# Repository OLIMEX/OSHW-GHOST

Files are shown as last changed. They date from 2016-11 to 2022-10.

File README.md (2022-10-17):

# OSHW-GHOST
Small SMT soldering kit with PIC10F206 re-programmable microcontroller, capacitive sensor and LEDs

## License
* Hardware is released under CERN Open Hardware Licence Version 2 - Strongly Reciprocal https://spdx.org/licenses/CERN-OHL-S-2.0.html
* Software is released under GPL3 License
* Documentation is released under CC BY-SA 4.0 https://creativecommons.org/licenses/by-sa/4.0/

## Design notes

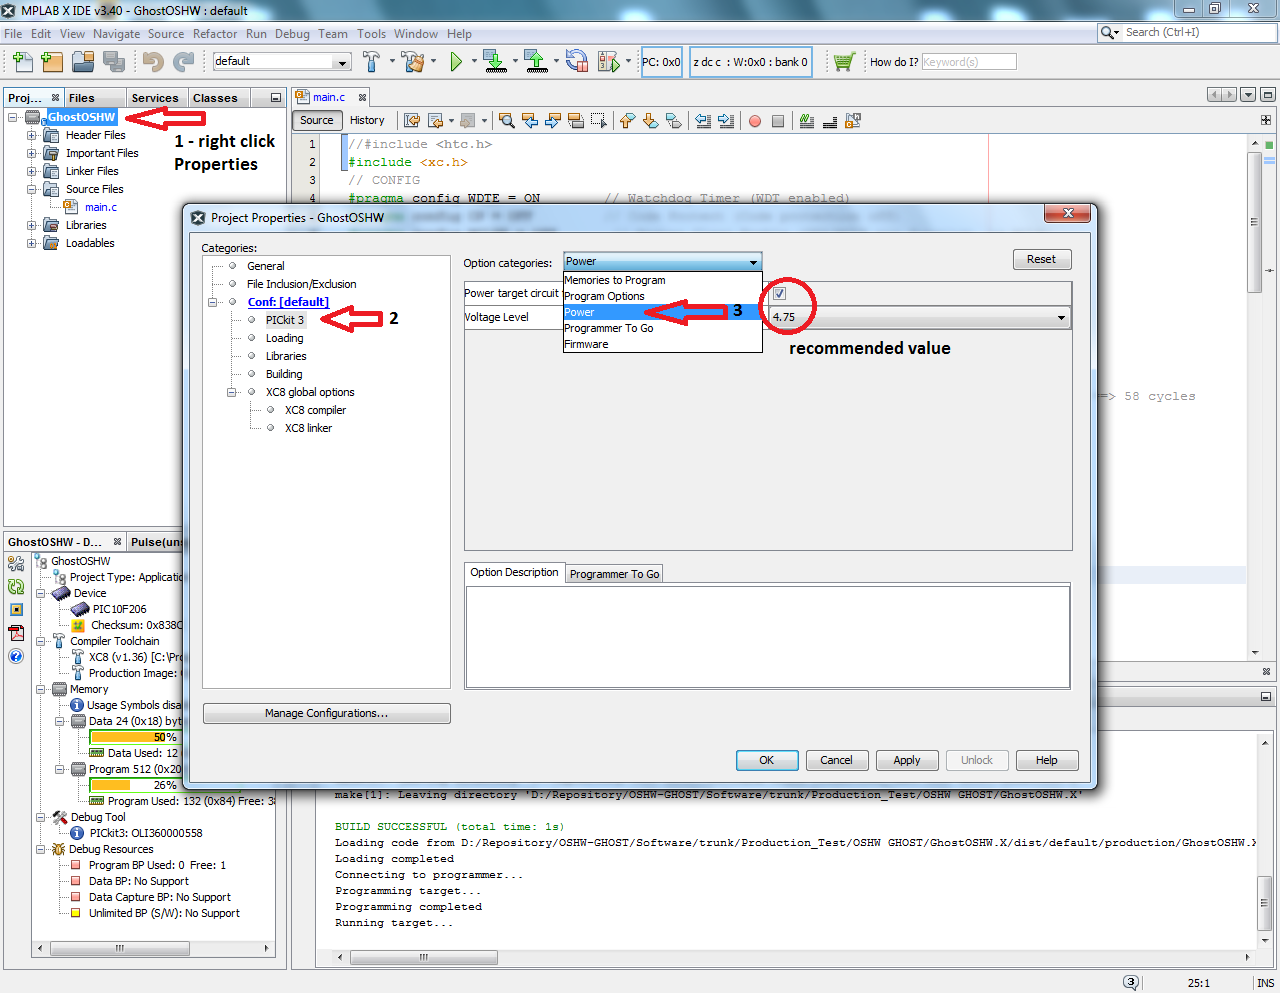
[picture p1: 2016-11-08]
SOFTWARE/voltage configuration.png

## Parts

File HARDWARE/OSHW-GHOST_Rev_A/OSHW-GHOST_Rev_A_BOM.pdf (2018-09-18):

### Sheet1

OSHW-GHOST_Rev_A
Quantity | Value | Device | Parts
1 | CR2032H_PTH | CR2032H_PTH | BAT_CON1
1 | 100nF/50V/20%/Y5V | C1206 | C1
1 | NA(WU06S) | ICSP-WU06S | ICSP1
2 | LED-3.0MM/GREEN | LED-3mm-PTH-KA | LED1,LED2
3 | 120R | R1206 | R1,R2,R4
1 | 1M | R1206 | R3
1 | NA(10k) | R1206 | R5
1 | PIC10F206T-I/OT | SOT23-6 | U1
1 | BADGE-PIN-CLIPS | BADGE-PIN-CLIPS | BPC1

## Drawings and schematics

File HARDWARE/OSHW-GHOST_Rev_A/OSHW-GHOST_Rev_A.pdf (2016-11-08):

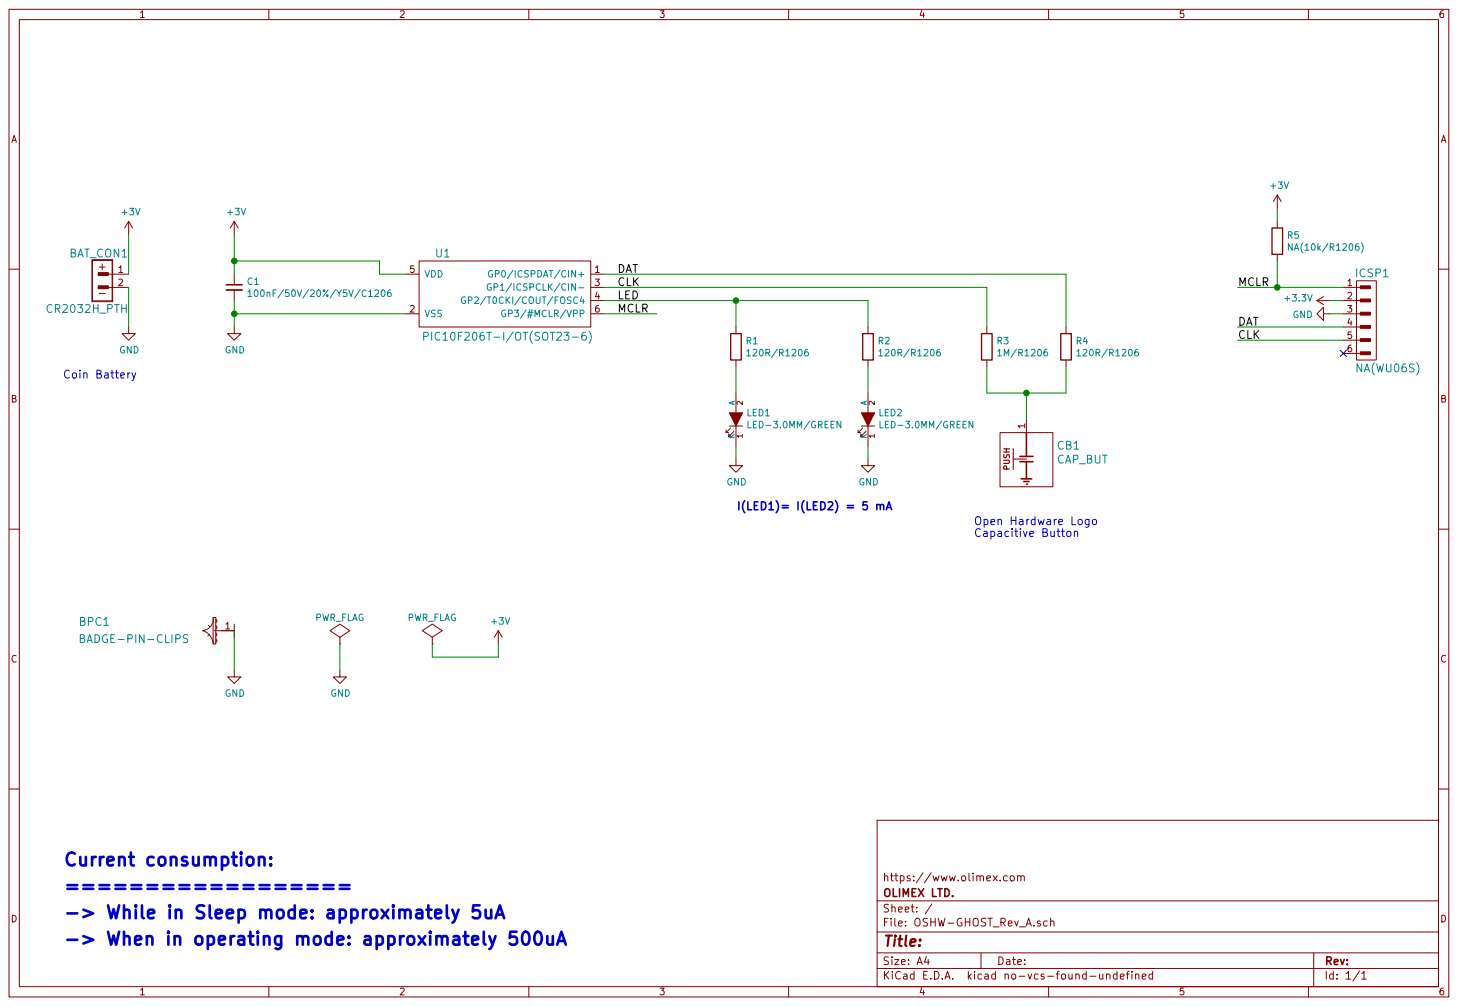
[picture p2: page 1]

NA(WU06S) R5NA(10k/R1206) +3.3V GND DAT CLK

File: OSHW-GHOST_Rev_A.sch Sheet: / OLIMEX LTD. https://www.olimex.com

-> While in Sleep mode: approximately 5uA
-> When in operating mode: approximately 500uA

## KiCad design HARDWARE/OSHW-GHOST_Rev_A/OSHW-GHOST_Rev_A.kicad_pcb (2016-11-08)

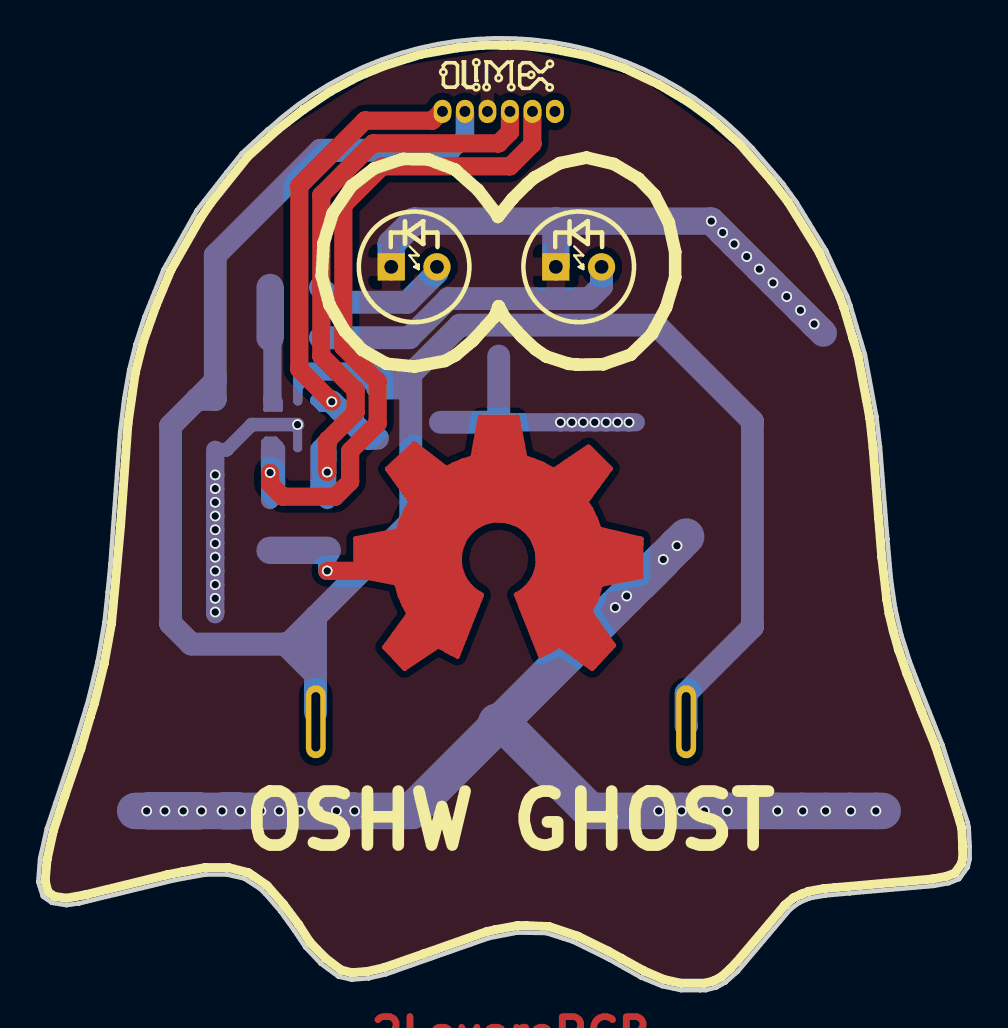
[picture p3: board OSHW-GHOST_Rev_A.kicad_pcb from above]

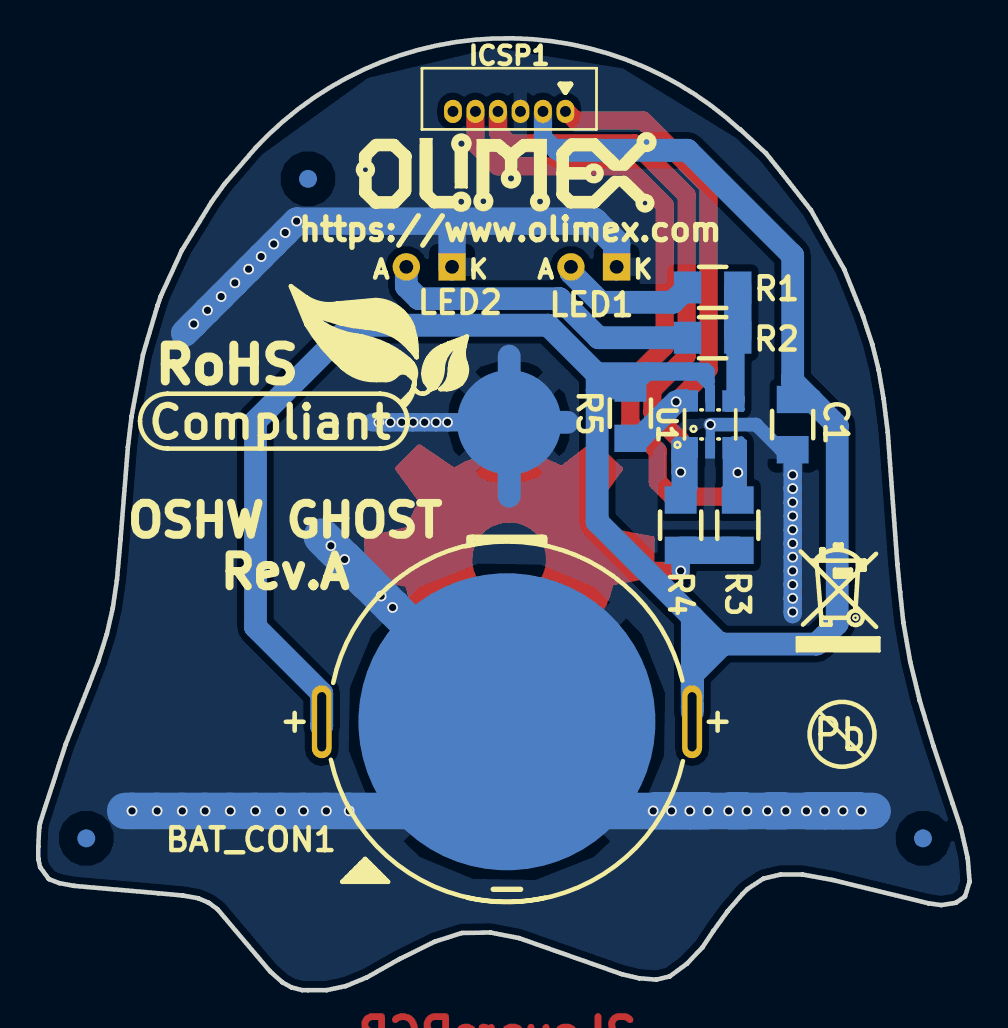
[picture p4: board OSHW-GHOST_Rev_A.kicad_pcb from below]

Board: 2 copper layers, 51.7 x 52.9 mm, 14 parts (11 on the bottom side), 9 nets.

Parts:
BAT_CON1: CR2032H_PTH
BPC1: BADGE-PIN-CLIPS
C1: 100nF/50V/20%/Y5V/C1206; C_1206_5MIL_DWS
CB1: CAP_BUT; CAP_BUT_LOGO_OPENHARDWARE_16x16
ICSP1: NA(WU06S); ICSP-WU06S
LED1, LED2: LED-3.0MM/GREEN; LED-3mm-PTH-KA
R1, R2, R4: 120R/R1206; R_1206_5MIL_DWS
R3: 1M/R1206; R_1206_5MIL_DWS
R5: NA(10k/R1206); R_1206_5MIL_DWS
Ref**: Val**; LOGO_ROHS_1
U1: PIC10F206T-I/OT(SOT23-6); SOT23-6

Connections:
+3V3: BAT_CON1.1, C1.1, ICSP1.2, R5.1, U1.5
/CLK: ICSP1.5, R3.1, U1.3
/DAT: ICSP1.4, R4.1, U1.1
/LED: R1.1, R2.1, U1.4
/MCLR: ICSP1.1, R5.2, U1.6
GND: BAT_CON1.2, BPC1.1, C1.2, ICSP1.3, LED1.1, LED2.1, U1.2
unnamed: CB1.1, R3.2, R4.2
unnamed: LED1.2, R1.2
unnamed: LED2.2, R2.2

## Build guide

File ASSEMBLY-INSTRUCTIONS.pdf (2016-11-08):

ASSEMBLY INSTRUCTIONS FOR OSHW-GHOST KIT

OSHW-GHOST is small open source hardware board, created to teach novices soldering SMT components. It’s easy to assembly and fun to use as it contain re-programmable PIC10F206 microcontroller which you can re-program yourself once you assembly the board.
Here is how the kit looks like:

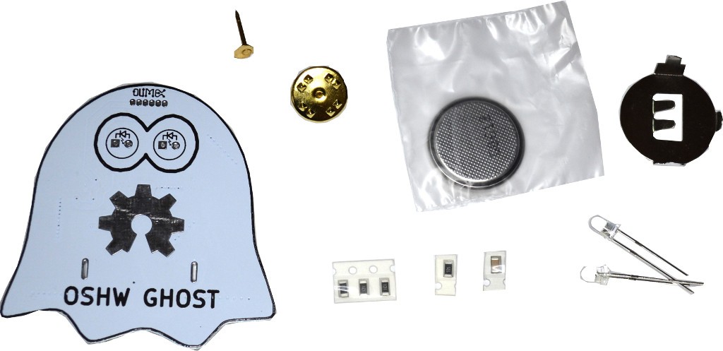
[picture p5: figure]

What you see is white printed circuit board, metal clip and pin which will allow you to attach this board to your cloths, battery and metal battery holder, 3 resistors one capacitor and two high intensity green LEDs with 3 mm diameter.

To solder this board you need:
- soldering iron, any with power 20-60W, thin tip and regulated temperature will do the job for instance this one; (https://www.olimex.com/Products/Tools/Soldering/CHN-SLD907/)
- solder with flux – we recommend to use 1 mm wire solder with 2.5% flux core;
- colophony (you can buy from any electronic store or music instruments store);
- tweezers like this one (https://www.olimex.com/Products/Tools/HandTools/CHN-TWZ2MM/) or similar;
- wire cutters like this one (https://www.olimex.com/Products/Tools/HandTools/PGC-TR25/) or similar;

Power up your soldering iron and set it to 300-350C temperature.
If you look at the PCB it comes with PIC microcontroller pre-soldered:

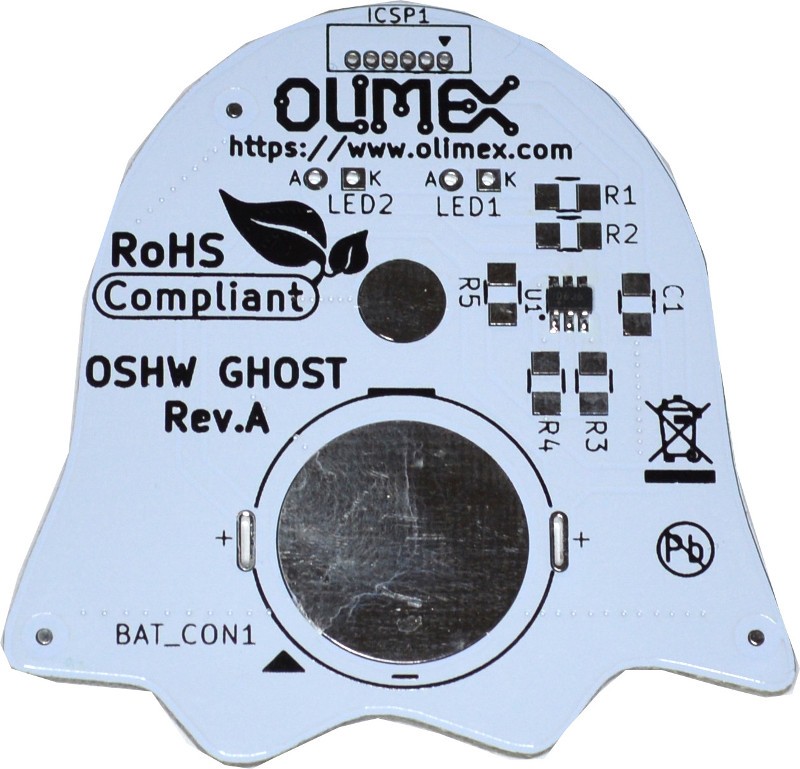
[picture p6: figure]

This is done intentionally for two reasons, first it’s hard to solder for novices, second to pre-program it we use the ICSP1 connector on top, to program this PIC microcontroller in bulk requires special adapter we do not have :)

First you find the brown rectangle component in the paper tape. This is 100 nF capacitor:

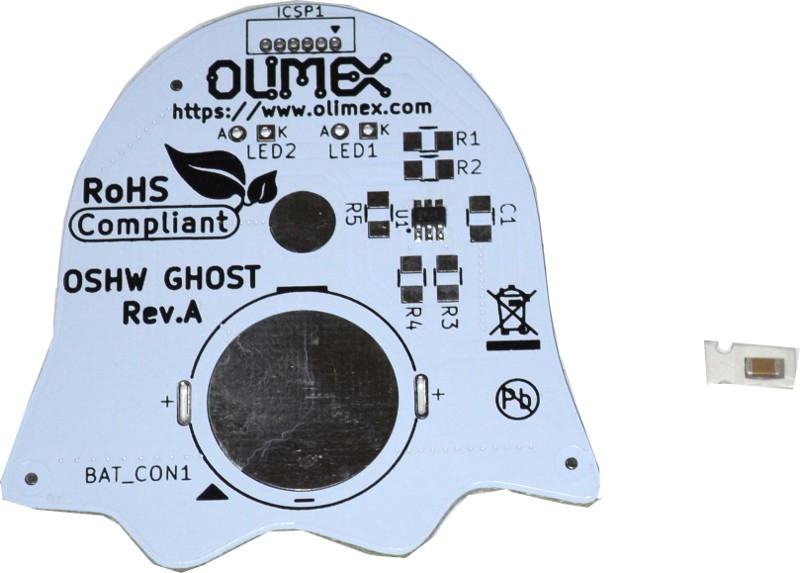
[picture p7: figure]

You must peel the transparent tape and take off the capacitor then to solder it to C1 pads on the board like on this picture.

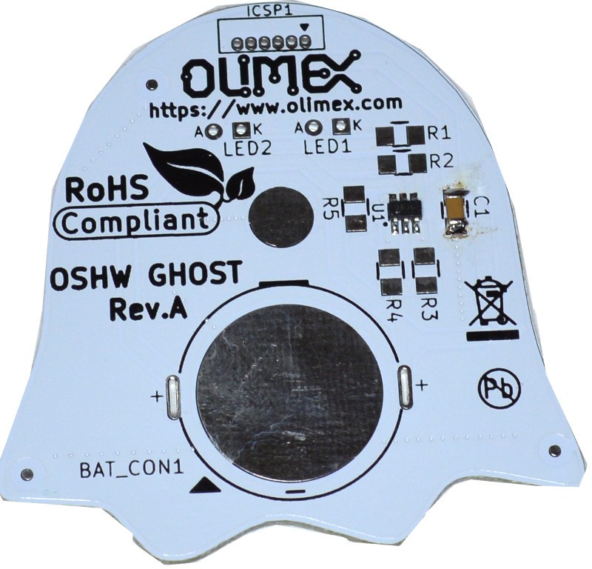
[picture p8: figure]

The colophony flux in the solder wire do a little messy look but do not worry, at the end you can use Isopropile or Ethyl alcohol with soft fabric to clean the flux residues. Even if not clean they are harmless for the board, just will not look pretty as the picture above :)

Once the capacitor is soldered at it’s place find the single black component in paper tape, it has marking 105. This is resistor with value 1 Mega Ohm. How this value 1Mega Ohm come from the 105 number? This three digit marking system for the resistor is composed by two digits and third which says how many zeros to add after the two digit so 105 = 10 00000 or 1 000 000 ohms (1Mega means 1 Million ohms). This resistor must be soldered at R3 pads on the PCB:

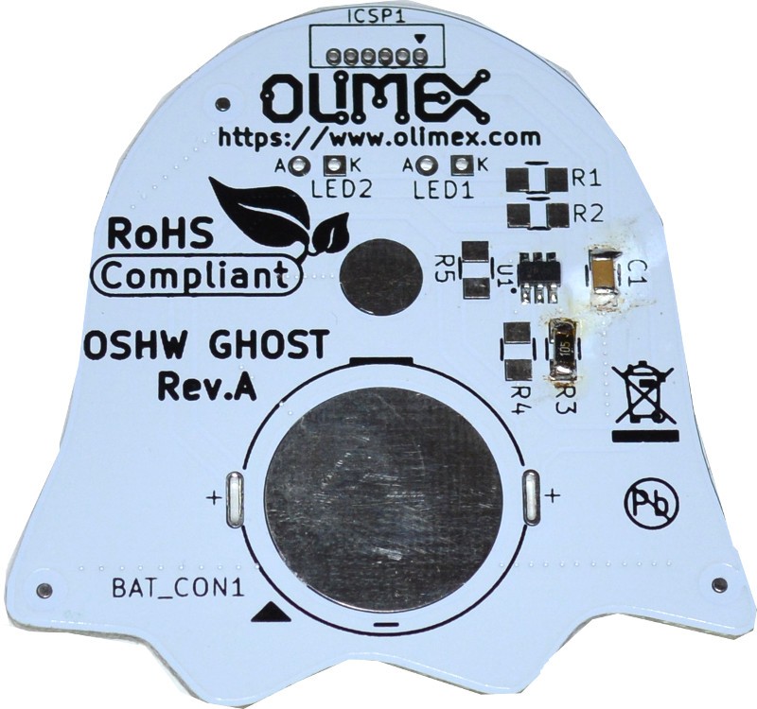
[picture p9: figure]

Then you need for find three resistors in paper tape, they are marked 121 = 120 or 120 Ohms! These must be soldered to R1, R2, and R4 locations:

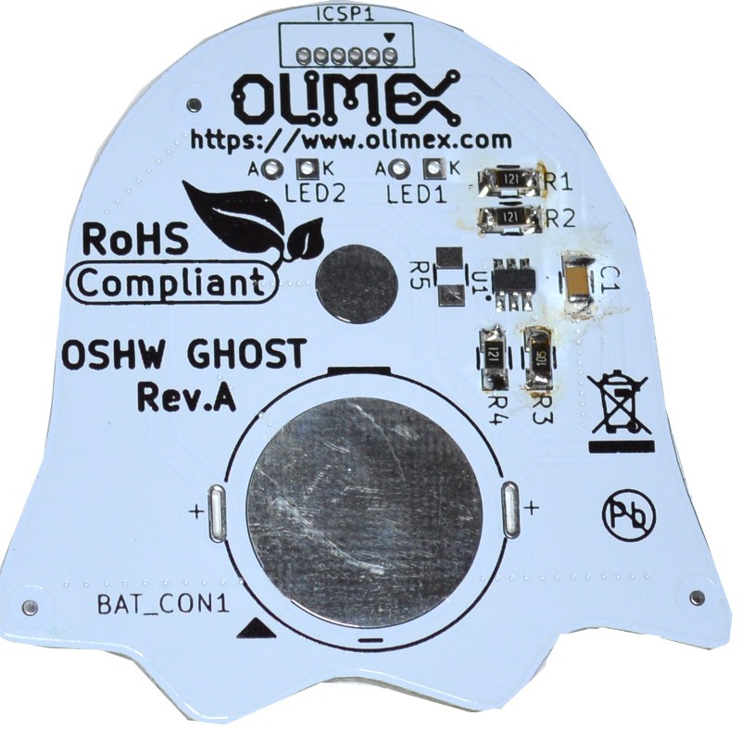
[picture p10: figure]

R5 and ICSP1 remains unpopulated, hey we soldered all SMT components, now to move to the omponents with legs.

General rule of thumb when assembly boards is to assembly first the shorter components then the taller ones as otherwise the tall components will make your assembly difficult.
We recommend now to solder first the battery holder, put it on th back side:

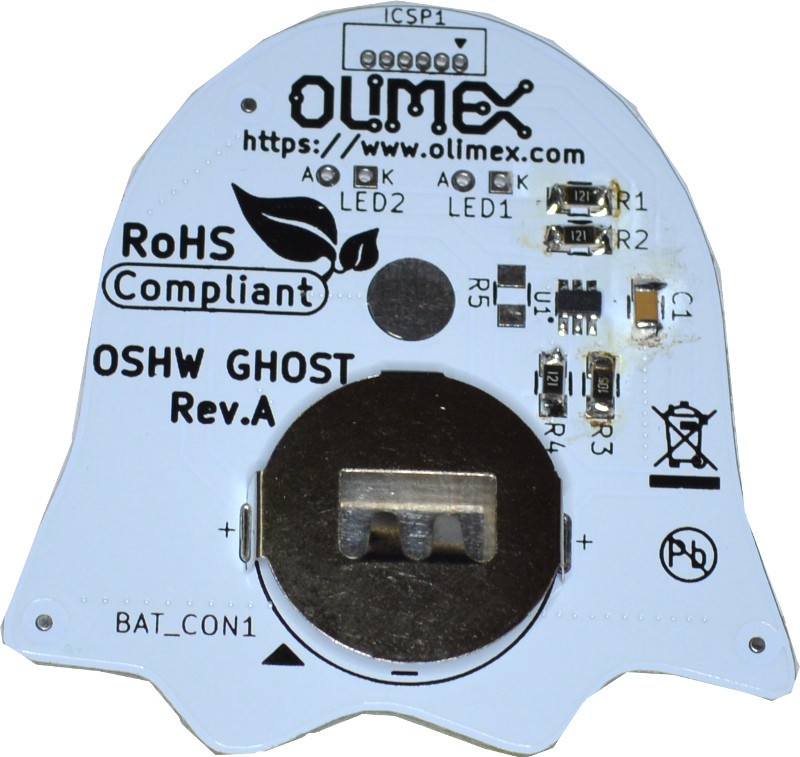
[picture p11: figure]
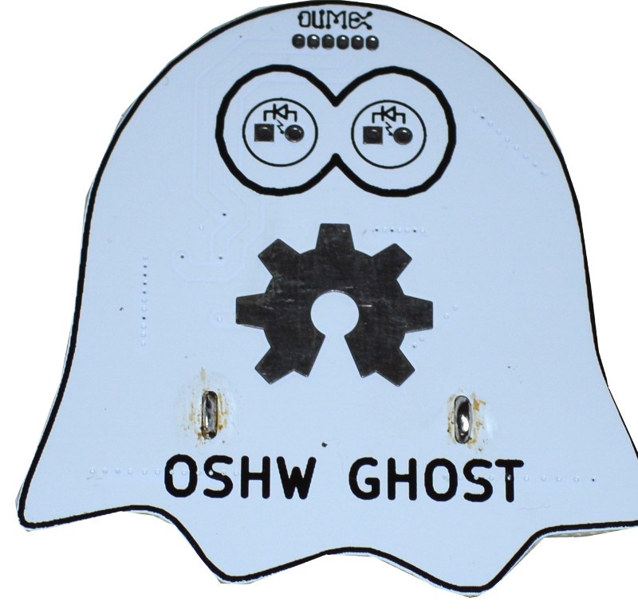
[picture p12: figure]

Then flip the PCB and solder the legs which are seen on front side:

Again do not worry about the flux residues. To solder the brass pin to the PCB first you have to tin it’s head, do not try to tin/solder it holding it with bare hand, use the tweezer for this purpose:

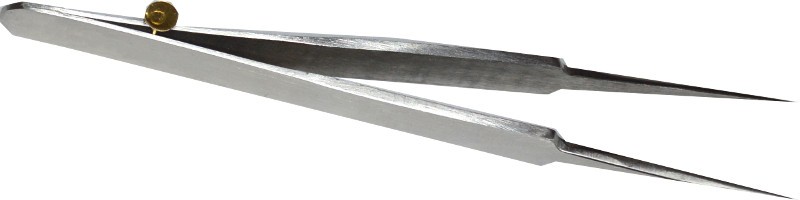
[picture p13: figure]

then touch the head of the pin with solder iron and add solder wire:

then using the tweezers hold the pin and solder it to the PCB:

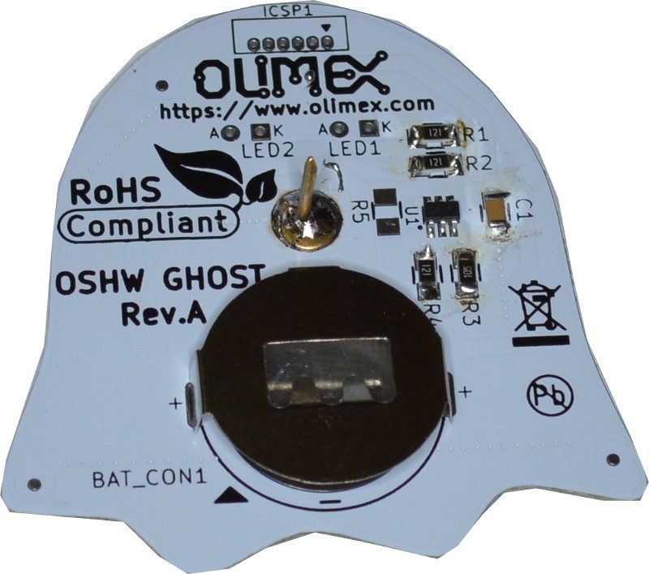
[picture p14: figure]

We are almost done! Now put the LEDs on their places, but note that they have POLARITY so you have to put them with the shorter leg inside the square pad (marked as K) and longer led in the circle pad (marked as A).

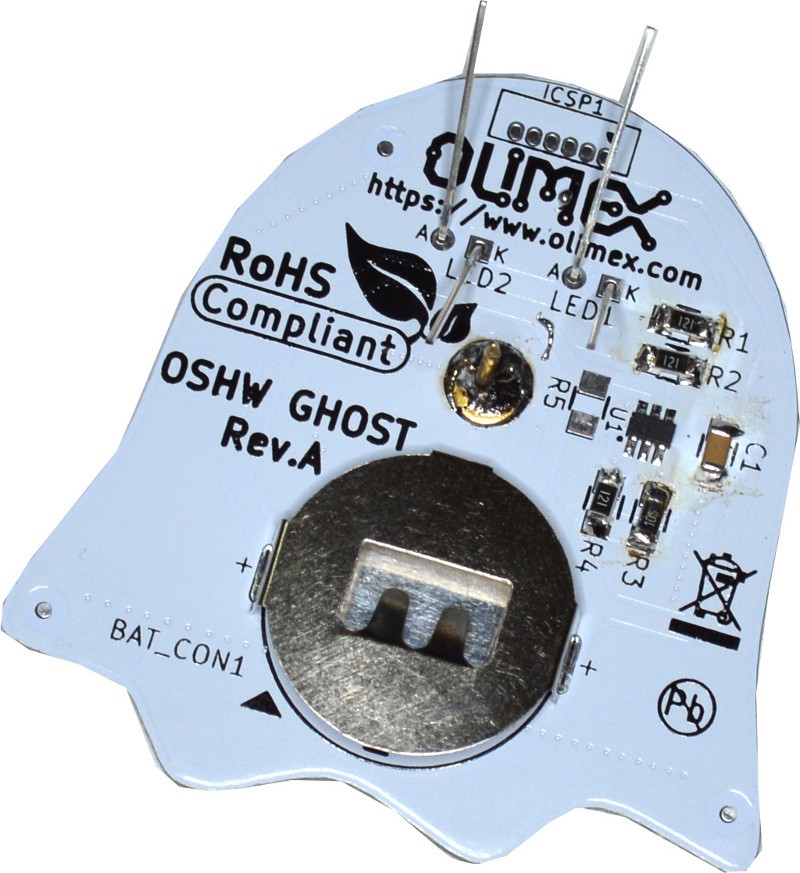
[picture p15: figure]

Then cut the legs with cutter and solder them:

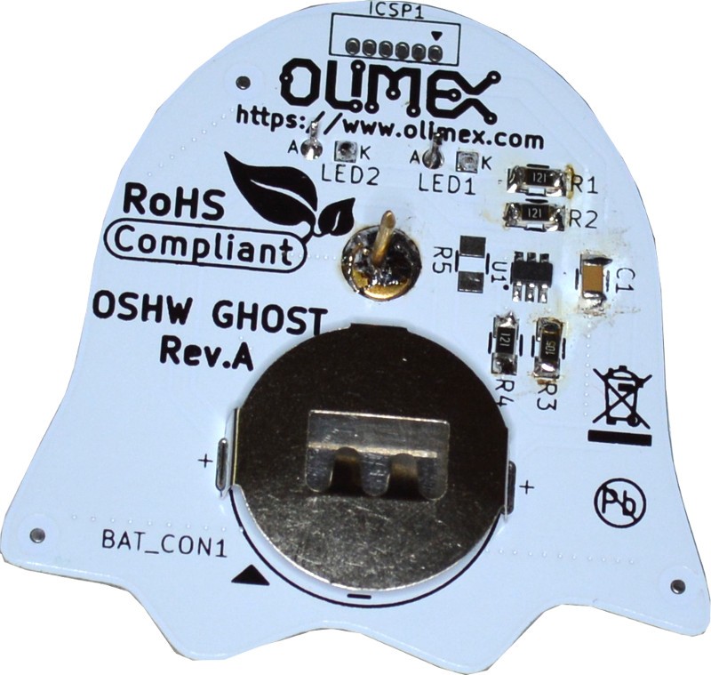
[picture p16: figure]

Now is time to attach the battery, again be careful as battery has polarity the + must be pointing UP as on this picture:

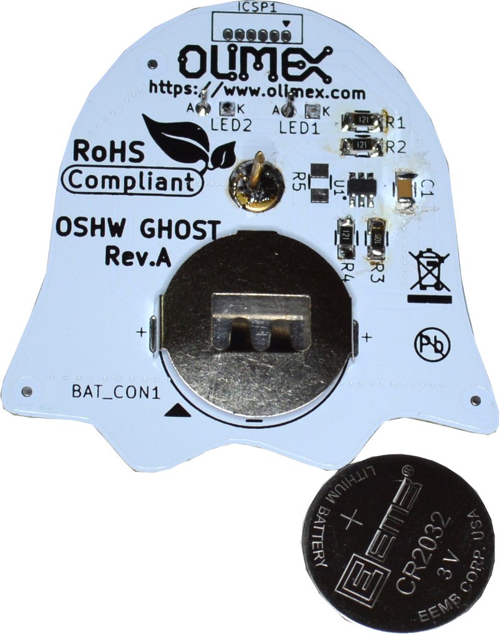
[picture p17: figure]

All set, if you now touch and hold the OSHW logo for 1 second you will see the green LEDs blinking, like on this video. (https://www.youtube.com/watch?v=qiagmQRXRTQ&feature=youtu.be)

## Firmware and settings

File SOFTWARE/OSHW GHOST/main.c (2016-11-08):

//#include <htc.h>
#include <xc.h>
// CONFIG
#pragma config WDTE = ON        // Watchdog Timer (WDT enabled)
#pragma config CP = OFF         // Code Protect (Code protection off)
#pragma config MCLRE = OFF       // Master Clear Enable (GP3/MCLR pin function  is MCLR)
#define	RESET_WATCHDOG()	{\
								asm ("CLRWDT");\
								OPTION = 0xDD;\
							}



#define	DELAY	5	// number of cycles with the same duty cycle
#define	CYCLES	(long int)DELAY * 256 * (2*NUMBER_OF_STEPS - 2);	// Index: 1-->29; 28-->0 ==> 58 cycles


#define	LED_ON	GPIO = GPIO | 0x04	// GPIO2 --> 1
#define	LED_OFF	GPIO = GPIO & 0xFB	// GPIO2 --> 0
void Delay (volatile unsigned int Period);
void Pulse (unsigned char NumberOfPulses)
{
	while (NumberOfPulses--)
	{


			RESET_WATCHDOG();
	
            LED_ON;
            Delay(32);
			LED_OFF;
            Delay(64);

	}
	return;
}

void Delay (volatile unsigned int Period)
{
 unsigned char a=255,b = Period;
 while (a--){
  b=Period;     
  while (--b)
		RESET_WATCHDOG();
 }   
}


char Button ()
{
	char Timer = 0, Counter;
	char Flag = 1;
	RESET_WATCHDOG();
	TRISGPIO = 0x09;
	//TRISGPIO = TRISGPIO & 0xFD;	// GPIO1 --> Output
	//TRISGPIO = TRISGPIO | 0x01;	// GPIO0 --> Input
	GPIO = GPIO & 0xFC;				// GPIO1 --> 0; GPIO0 --> 0
	GPIO = 0x02;	// GPIO1 --> 1
	RESET_WATCHDOG();
	Timer = 0;
	while (!(GPIO & 0x01))	// wait until GPIO0 is 1 and count the time
		Timer++;
	RESET_WATCHDOG();

	if (Timer < 2)		// if the time is less than 2 units the capacity button isn't touched
		Flag = 0;
	TRISGPIO = 0x08;	// GPIO1 --> Output; GPIO0 --> Output
	GPIO = GPIO & 0xFC;			// GPIO1 --> 0; GPIO0 --> 0;
	Delay (100);
	RESET_WATCHDOG();
	TRISGPIO = 0x09;
	RESET_WATCHDOG();
	return Flag;
}

int main ()
{
	RESET_WATCHDOG();
	TRISGPIO = 0x08;
    CMCON0 = 0xF7;    //CMPON = 0x00;
	RESET_WATCHDOG();
	if (Button())
		Pulse (10);
	RESET_WATCHDOG();
	TRISGPIO = 0x08;
	RESET_WATCHDOG();
	GPIO = 0;
	asm("SLEEP");
	return 0;
}

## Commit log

2016-11-08 Initial file upload
    [OSHW-GHOST_Rev_A-B.Cu.gbr, OSHW-GHOST_Rev_A-B.Mask.gbr, OSHW-GHOST_Rev_A-B.Paste.gbr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]
2018-09-18 Update
    PDF BOM
